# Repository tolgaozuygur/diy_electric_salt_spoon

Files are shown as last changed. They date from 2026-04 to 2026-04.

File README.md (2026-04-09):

# DIY Electric Salt Spoon
A DIY electro-gustation spoon that artificially increases the salty taste of foods using microscopic electric currents. Inspired by Kirin's Electric Salt Spoon and built as an open-source version to test the concept. Watch the <a href="https://www.youtube.com/watch?v=7jDd-lppwBE" target="_blank">build and testing video on YouTube</a> (EN subs available).

## Some components used not mentioned in the source files:
- 1mm 316L stainless steel wire in the spoon tip (to lower the risk of electrolysis and corrosion)
- 1mm copper plate as the hand electrode
- 12V 23A battery (small batteries commonly used in remotes)

## Scientific Background & Inspiration
The waveform blueprint and the core concept of this project are based on the electro-gustation research conducted by Miyashita Laboratory (Meiji University) and Kirin Holdings. 
You can read the original paper here:
- [Design of Electrical Stimulation Waveform for Enhancing Saltiness and Experiment on Low-Sodium Dieters](https://www.frontiersin.org/journals/virtual-reality/articles/10.3389/frvir.2022.879784/full) (Kaji, Sato, & Miyashita, 2022)

> ## ⚠️ SAFETY WARNING & DISCLAIMER
> **BUILD AND USE AT YOUR OWN RISK.**
> 
> This project involves passing an electrical current directly through the human body (specifically, from the hand to the tongue) to pull sodium ions towards your tongue for an increase in saltiness. While the circuit is designed with hardware current-limiting features to keep this current at microscopic, safe levels, human error in assembly can result in injury.
> 
> **CRITICAL POWER SUPPLY RULE:**
> When applying this device to a person, it must **ONLY** be powered by a small **12V 23A battery**. 
> * **NEVER** connect this device to a human while it is plugged into a USB port, a wall adapter, a bench power supply, or a high-current battery (like a standard 9V or LiPo). 
> * Doing so risks bypassing the safety limits, which can cause severe pain, chemical burns on the tongue, or serious electrical injury.
> 
> **Always test your fully assembled circuit with a multimeter** (you can place a 10kΩ resistor across the electrodes to simulate the hand-to-tongue resistance) to verify the output current is within the expected micro-amp range before ever letting it touch your skin or mouth.

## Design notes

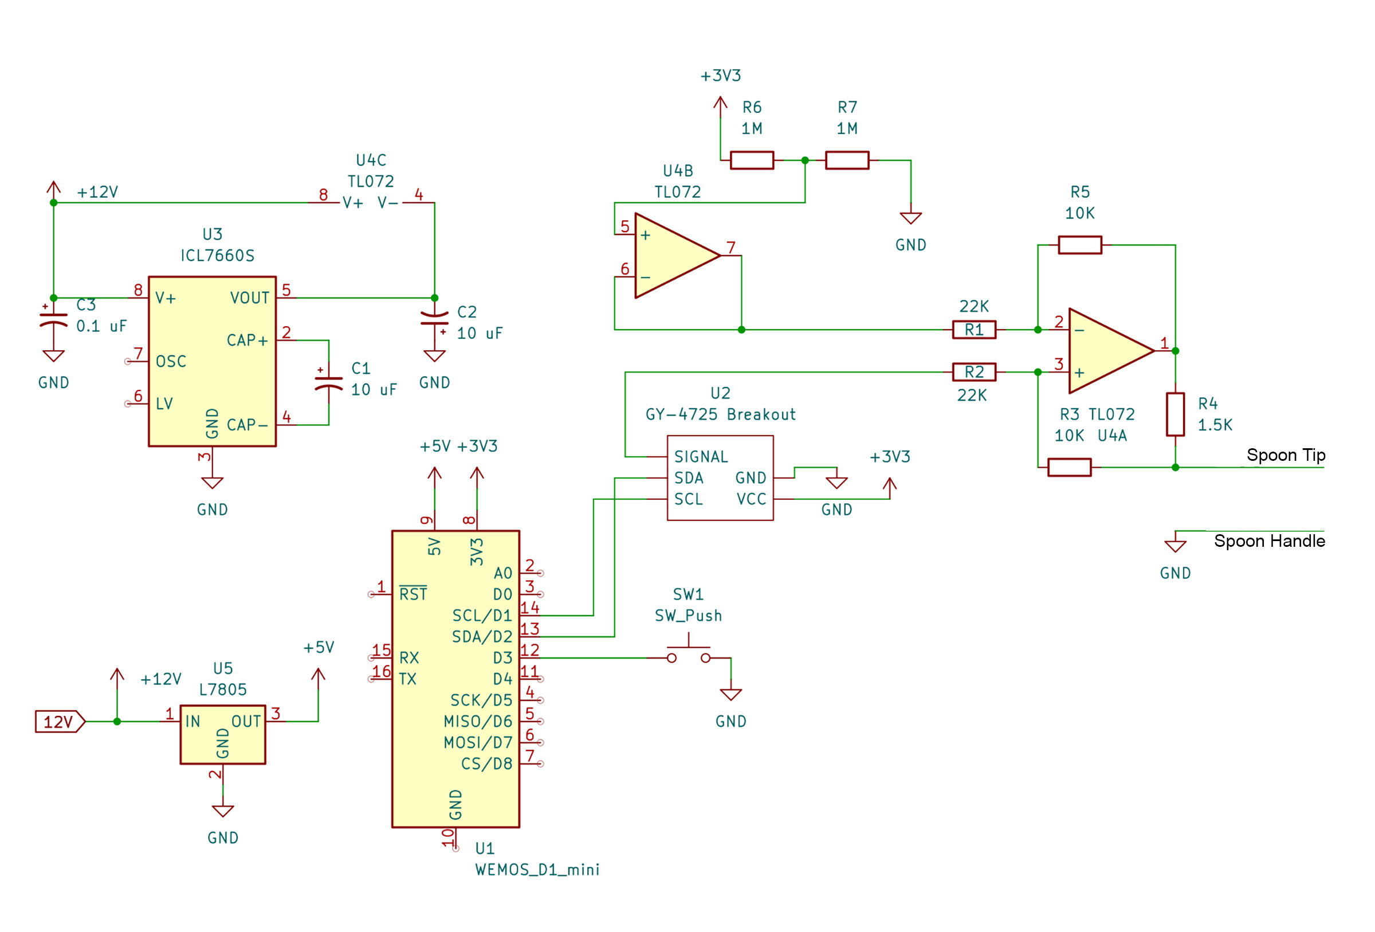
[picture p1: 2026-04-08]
electronics/schematics.jpg

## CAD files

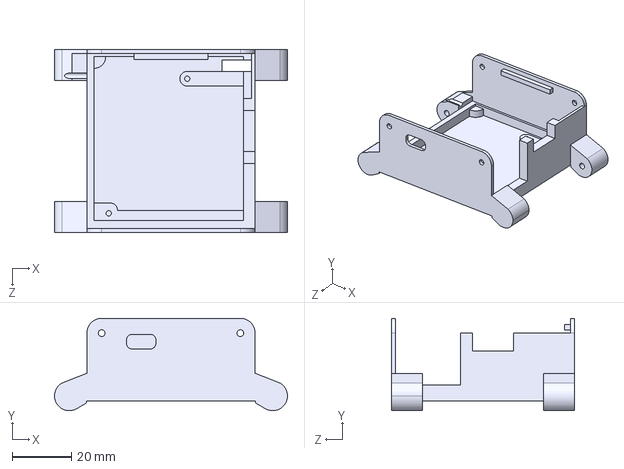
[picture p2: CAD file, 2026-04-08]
3d/case_base.STEP
78.9 x 31.3 x 62.0 mm

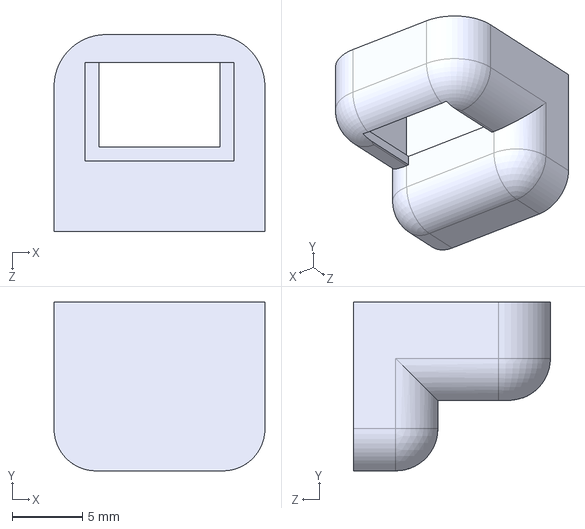
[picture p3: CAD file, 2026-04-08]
3d/spoon_socket_holder.STEP
15.0 x 12.0 x 14.0 mm

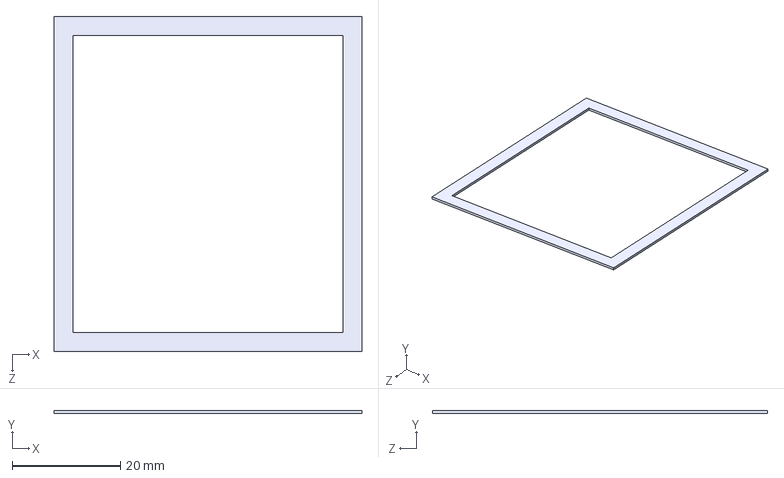
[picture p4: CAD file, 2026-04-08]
3d/case_electrode_mount.STEP
57.0 x 0.6 x 62.0 mm

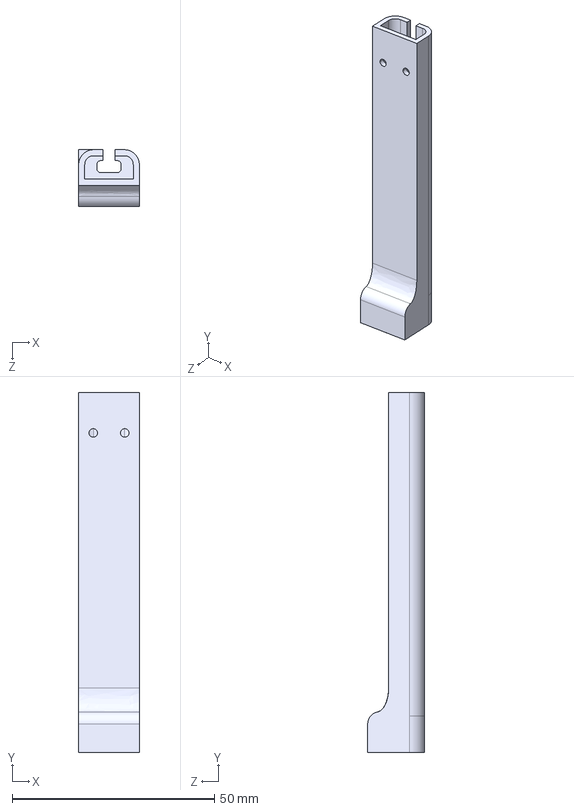
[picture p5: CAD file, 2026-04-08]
3d/spoon_middle.STEP
15.0 x 89.0 x 14.0 mm

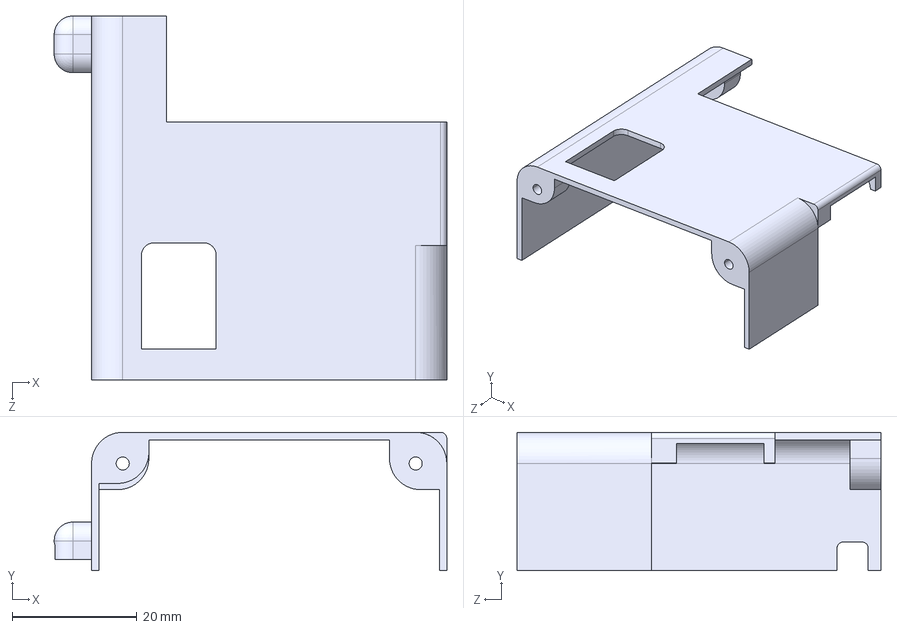
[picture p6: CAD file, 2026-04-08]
3d/case_cover.STEP
63.0 x 22.2 x 58.4 mm

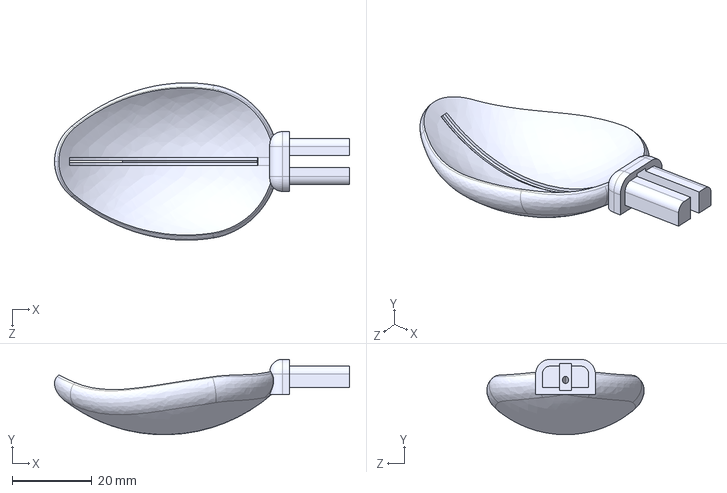
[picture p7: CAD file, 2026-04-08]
3d/spoon_tip.STEP
74.0 x 18.9 x 39.4 mm

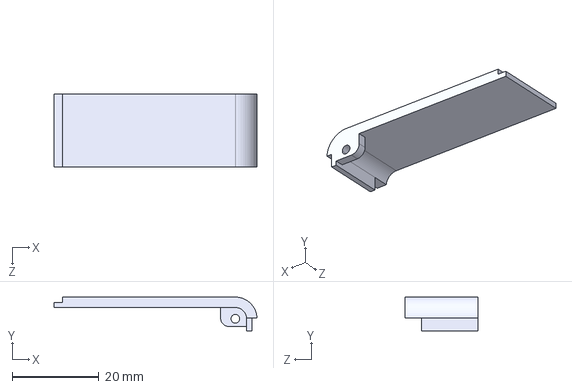
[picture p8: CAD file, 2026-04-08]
3d/battery_cap.STEP
46.8 x 7.80 x 16.8 mm

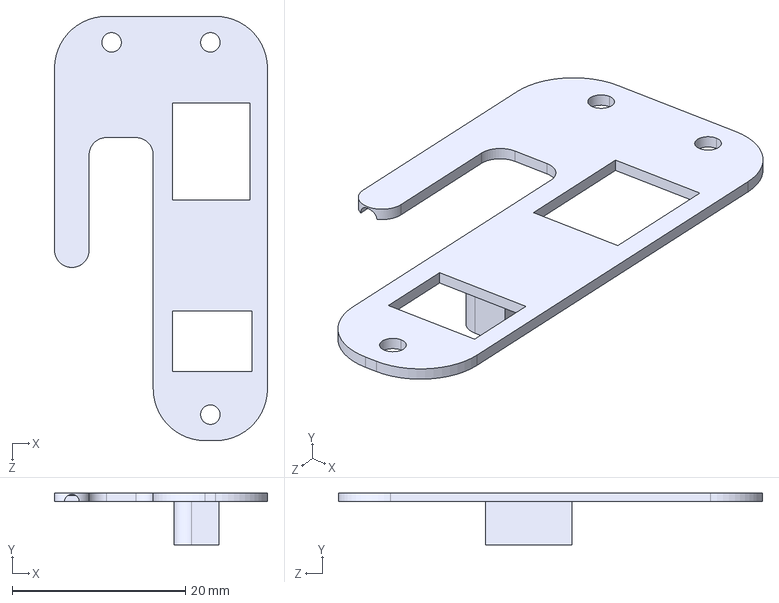
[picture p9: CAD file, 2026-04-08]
3d/cup_electrode_cover.STEP
24.6 x 6.00 x 49.0 mm

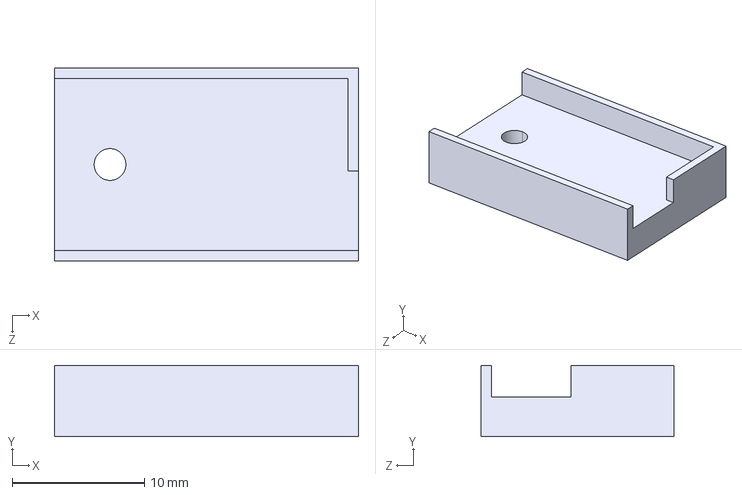
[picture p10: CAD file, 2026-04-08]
3d/battery_mount.STEP
23.0 x 5.40 x 14.6 mm

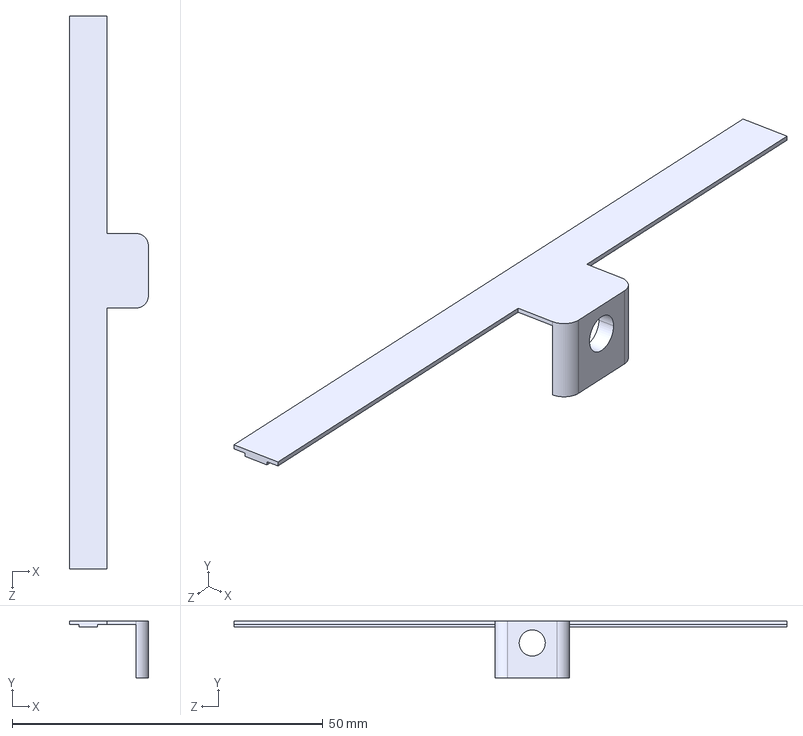
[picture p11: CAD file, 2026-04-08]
3d/spoon_stripe.STEP
12.7 x 9.10 x 89.0 mm

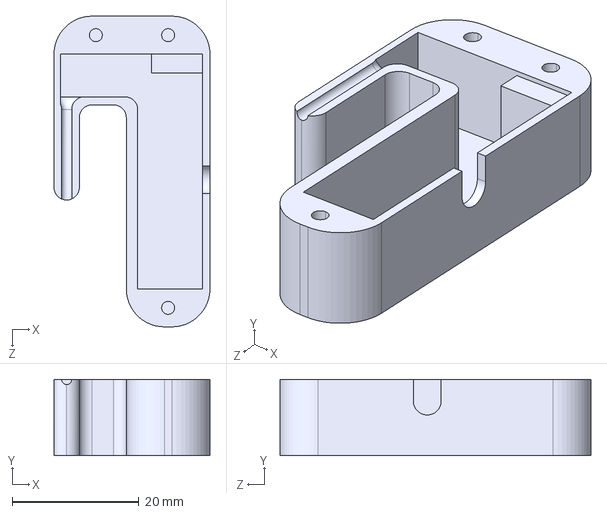
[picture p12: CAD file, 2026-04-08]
3d/cup_electrode.STEP
24.6 x 12.0 x 49.0 mm

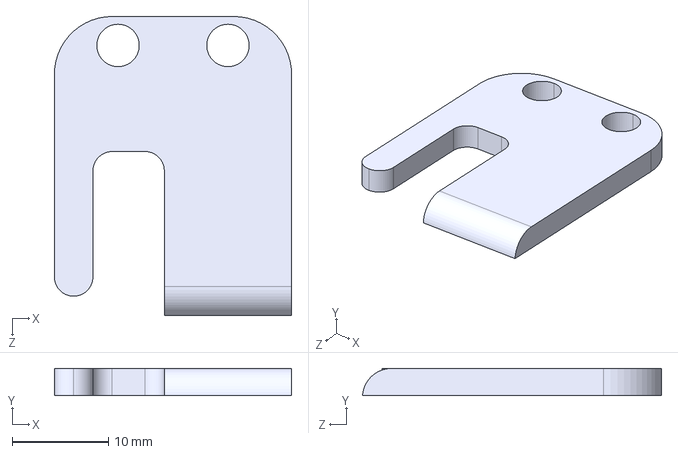
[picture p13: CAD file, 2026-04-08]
3d/cup_electrode_coverB.STEP
24.6 x 2.80 x 31.0 mm

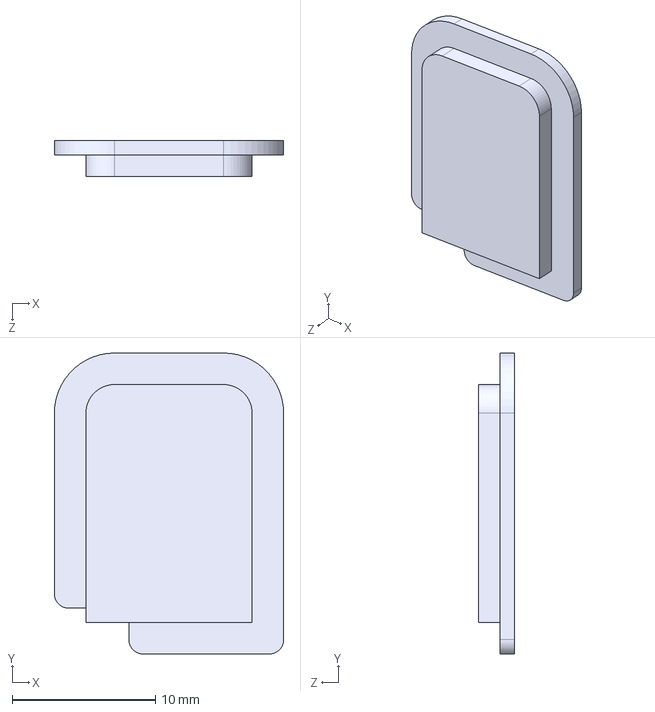
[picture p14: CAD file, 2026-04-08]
3d/case_window.STEP
16.0 x 21.0 x 2.50 mm

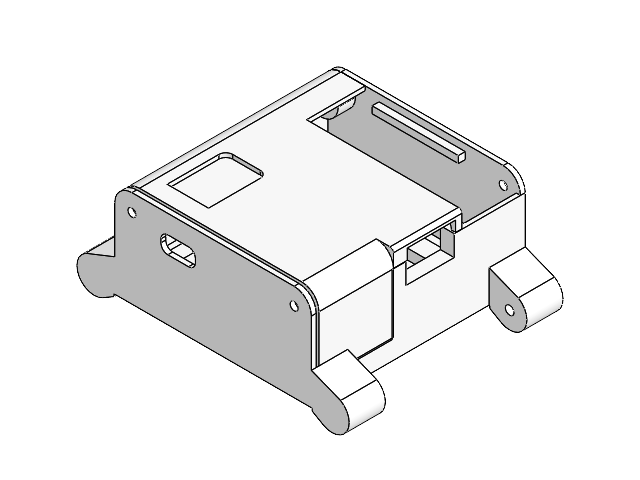
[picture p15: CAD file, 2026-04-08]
3d/spooncaseAssemb.SLDASM
case_base
case_cover

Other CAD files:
3d/spoonAssembly.SLDASM
3d/battery_cap.SLDPRT
3d/battery_mount.SLDPRT
3d/case_base.SLDPRT
3d/case_cover.SLDPRT
3d/case_electrode_mount.SLDPRT
3d/case_window.SLDPRT
3d/cup_electrode.SLDPRT
3d/cup_electrode_cover.SLDPRT
3d/cup_electrode_coverB.SLDPRT
3d/spoon_middle.SLDPRT
3d/spoon_socket_holder.SLDPRT
3d/spoon_stripe.SLDPRT
3d/spoon_tip.SLDPRT

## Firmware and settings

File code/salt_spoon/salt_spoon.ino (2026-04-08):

#include <Wire.h>
#include <Adafruit_MCP4725.h>
#include <ESP8266WiFi.h>
#include <ESP8266WebServer.h>
#include <EEPROM.h>
#include <math.h> 

extern "C" {
  #include "user_interface.h" 
}

#define DEBUG_MODE 0 

// --- ACCESS POINT CONFIGURATION ---
const char* ap_ssid = "SaltSpoon_Config";
const char* ap_password = "12345678";

// --- HARDWARE PINS ---
const int BUTTON_PIN = D3; 

Adafruit_MCP4725 dac;
static const uint8_t DAC_ADDR = 0x61; 
ESP8266WebServer server(80);

// --- HARDWARE CALIBRATION & EEPROM LIMITS ---
static const uint16_t DAC_MID = 1883;

// Master limits and defaults
static const float DEFAULT_CATHODAL_MA   = 0.50;
static const float MAX_CATHODAL_MA       = 0.57;

static const float DEFAULT_ANODAL_MA     = 0.67;
static const float MAX_ANODAL_MA         = 0.67;

static const uint16_t DEFAULT_REPEATS    = 1;
static const uint16_t MAX_REPEATS        = 20;

static const float DEFAULT_WAVE_SPEED    = 1.0;
static const float MIN_WAVE_SPEED        = 0.5;
static const float MAX_WAVE_SPEED        = 2.0;

static const uint16_t DEFAULT_ANODAL_MULT = 1;
static const uint16_t MIN_ANODAL_MULT     = 1;
static const uint16_t MAX_ANODAL_MULT     = 4;

// EEPROM Memory Addresses (Explicit byte mapping for safety)
const int addr_cathodal    = 0;   // float (4 bytes)
const int addr_anodal      = 4;   // float (4 bytes)
const int addr_repeats     = 8;   // uint16_t (2 bytes)
const int addr_speed       = 10;  // float (4 bytes)
const int addr_anodal_mult = 14;  // uint16_t (2 bytes)

// These will be loaded from EEPROM on boot
float target_cathodal_ma   = DEFAULT_CATHODAL_MA; 
float target_anodal_ma     = DEFAULT_ANODAL_MA;   
uint16_t target_repeats    = DEFAULT_REPEATS;
float wave_speed           = DEFAULT_WAVE_SPEED;
uint16_t anodal_multiplier = DEFAULT_ANODAL_MULT;

uint16_t intensity_cathodal = 0;
uint16_t intensity_anodal = 0;

// Update the step calculation whenever sliders change
void updateIntensities() {
  uint32_t c_steps = target_cathodal_ma * 3263.0;
  intensity_cathodal = constrain(c_steps, 0, 1859); 
  
  uint32_t a_steps = target_anodal_ma * 3263.0;
  intensity_anodal = constrain(a_steps, 0, 2187);   
}

// ── Base Waveform Timing (ms) ────────────────────────────────────────────────
static const uint32_t T_EASE_IN    = 300;  
static const uint32_t T_CATHODAL   = 500;  
static const uint32_t T_TRANSITION = 400;  
static const uint32_t T_ANODAL     = 500;  
static const uint32_t T_EASE_OUT   = 100;
static const uint32_t T_REST       = 100;

static const uint16_t EASE_STEPS   = 30;   
static const uint16_t RAMP_STEPS   = 40;   
// ─────────────────────────────────────────────────────────────────────────────

bool isConfigMode = false;

void setDAC(uint16_t value) {
  dac.setVoltage(constrain(value, 0, 4095), false);
}

// --- HTML WEB PAGE & SERVER LOGIC ---
void handleRoot() {
  String html = "<!DOCTYPE html><html><head><meta name='viewport' content='width=device-width, initial-scale=1.0'>";
  html += "<style>";
  html += "body { font-family: sans-serif; background-color: #f4f4f9; color: #333; padding: 20px; text-align: center; }";
  html += "h2 { color: #0056b3; }";
  html += ".card { background: white; padding: 20px; border-radius: 10px; box-shadow: 0 4px 8px rgba(0,0,0,0.1); margin-bottom: 20px; }";
  html += "input[type=range] { width: 100%; margin: 15px 0; }";
  html += "button { border: none; padding: 15px 20px; font-size: 16px; border-radius: 5px; cursor: pointer; width: 100%; font-weight: bold; margin-bottom: 10px; color: white;}";
  html += ".btn-save { background-color: #28a745; }";
  html += ".btn-save:active { background-color: #218838; }";
  html += ".btn-reset { background-color: #dc3545; }";
  html += ".btn-reset:active { background-color: #c82333; }";
  html += ".value-label { font-weight: bold; color: #d9534f; font-size: 1.2em; }";
  html += "</style></head><body>";
  
  html += "<h2>DIY Electric Salt Spoon</h2>";
  html += "<form action='/save' method='POST'>";
  
  // Cathodal Slider
  html += "<div class='card'>";
  html += "<label>Cathodal Phase (Negative Pull)</label><br>";
  html += "<span>Current: </span><span id='c_val' class='value-label'>" + String(target_cathodal_ma, 2) + "</span><span class='value-label'> mA</span>";
  html += "<input type='range' id='c_slider' name='cathodal' min='0.0' max='" + String(MAX_CATHODAL_MA, 2) + "' step='0.01' value='" + String(target_cathodal_ma, 2) + "' oninput=\"document.getElementById('c_val').innerText = this.value\">";
  html += "<small>Max limit: " + String(MAX_CATHODAL_MA, 2) + " mA</small>";
  html += "</div>";

  // Anodal Slider
  html += "<div class='card'>";
  html += "<label>Anodal Phase (Positive Push)</label><br>";
  html += "<span>Current: </span><span id='a_val' class='value-label'>" + String(target_anodal_ma, 2) + "</span><span class='value-label'> mA</span>";
  html += "<input type='range' id='a_slider' name='anodal' min='0.0' max='" + String(MAX_ANODAL_MA, 2) + "' step='0.01' value='" + String(target_anodal_ma, 2) + "' oninput=\"document.getElementById('a_val').innerText = this.value\">";
  html += "<small>Max limit: " + String(MAX_ANODAL_MA, 2) + " mA</small>";
  html += "</div>";

  // Repeats Slider
  html += "<div class='card'>";
  html += "<label>Waveform Repeats</label><br>";
  html += "<span>Cycles: </span><span id='r_val' class='value-label'>" + String(target_repeats) + "</span><span class='value-label'>x</span>";
  html += "<input type='range' id='r_slider' name='repeats' min='1' max='" + String(MAX_REPEATS) + "' step='1' value='" + String(target_repeats) + "' oninput=\"document.getElementById('r_val').innerText = this.value\">";
  html += "<small>Continuous loops</small>";
  html += "</div>";

  // Speed Slider
  html += "<div class='card'>";
  html += "<label>Global Wave Speed</label><br>";
  html += "<span>Speed: </span><span id='s_val' class='value-label'>" + String(wave_speed, 1) + "</span><span class='value-label'>x</span>";
  html += "<input type='range' id='s_slider' name='speed' min='" + String(MIN_WAVE_SPEED, 1) + "' max='" + String(MAX_WAVE_SPEED, 1) + "' step='0.1' value='" + String(wave_speed, 1) + "' oninput=\"document.getElementById('s_val').innerText = this.value\">";
  html += "<small>1.0x is normal, 2.0x is double speed</small>";
  html += "</div>";

  // Anodal Hold Multiplier Slider
  html += "<div class='card'>";
  html += "<label>Anodal Hold Duration</label><br>";
  html += "<span>Multiplier: </span><span id='am_val' class='value-label'>" + String(anodal_multiplier) + "</span><span class='value-label'>x</span>";
  html += "<input type='range' id='am_slider' name='anodal_mult' min='" + String(MIN_ANODAL_MULT) + "' max='" + String(MAX_ANODAL_MULT) + "' step='1' value='" + String(anodal_multiplier) + "' oninput=\"document.getElementById('am_val').innerText = this.value\">";
  html += "<small>Extends the positive push phase duration (1x to 4x)</small>";
  html += "</div>";

  // Action Buttons
  html += "<button type='submit' name='action' value='save' class='btn-save'>Save to Device Memory</button>";
  html += "<button type='submit' name='action' value='reset' class='btn-reset'>Reset to Defaults</button>";
  html += "</form>";
  html += "</body></html>";
  
  server.send(200, "text/html", html);
}

void handleSave() {
  if (server.hasArg("action")) {
    String action = server.arg("action");
    
    if (action == "reset") {
      // Apply Defaults
      target_cathodal_ma = DEFAULT_CATHODAL_MA;
      target_anodal_ma   = DEFAULT_ANODAL_MA;
      target_repeats     = DEFAULT_REPEATS;
      wave_speed         = DEFAULT_WAVE_SPEED;
      anodal_multiplier  = DEFAULT_ANODAL_MULT;
    } 
    else if (action == "save" && server.hasArg("cathodal") && server.hasArg("anodal") && server.hasArg("repeats") && server.hasArg("speed") && server.hasArg("anodal_mult")) {
      // Apply custom slider values with safety clamps
      target_cathodal_ma = constrain(server.arg("cathodal").toFloat(), 0.0, MAX_CATHODAL_MA);
      target_anodal_ma   = constrain(server.arg("anodal").toFloat(), 0.0, MAX_ANODAL_MA);
      target_repeats     = constrain(server.arg("repeats").toInt(), 1, MAX_REPEATS);
      wave_speed         = constrain(server.arg("speed").toFloat(), MIN_WAVE_SPEED, MAX_WAVE_SPEED);
      anodal_multiplier  = constrain(server.arg("anodal_mult").toInt(), MIN_ANODAL_MULT, MAX_ANODAL_MULT);
    }

    // Write everything to EEPROM
    EEPROM.put(addr_cathodal, target_cathodal_ma);
    EEPROM.put(addr_anodal, target_anodal_ma);
    EEPROM.put(addr_repeats, target_repeats); 
    EEPROM.put(addr_speed, wave_speed);
    EEPROM.put(addr_anodal_mult, anodal_multiplier);
    EEPROM.commit();
    
    // Recalculate DAC steps
    updateIntensities();
    
    // Success feedback
    String message = (action == "reset") ? "Factory Reset Complete!" : "Saved Successfully!";
    String html = "<html><head><meta name='viewport' content='width=device-width, initial-scale=1.0'><meta http-equiv='refresh' content='1;url=/'></head>";
    html += "<body style='font-family: sans-serif; text-align: center; padding: 50px;'>";
    html += "<h2 style='color: #28a745;'>" + message + "</h2><p>Returning to dashboard...</p></body></html>";
    server.send(200, "text/html", html);
  } else {
    server.send(400, "text/plain", "Bad Request");
  }
}

// --- WAVEFORM EXECUTION ---
void fireWaveform() {
  const uint16_t val_rest     = DAC_MID;
  const uint16_t val_cathodal = DAC_MID - intensity_cathodal;
  const uint16_t val_anodal   = DAC_MID + intensity_anodal;
  
  // Apply global wave_speed multiplier to step timings
  uint32_t ease_step_us  = ((T_EASE_IN * 1000) / EASE_STEPS) / wave_speed;
  uint32_t trans_step_us = ((T_TRANSITION * 1000) / RAMP_STEPS) / wave_speed;

  for (uint16_t i = 0; i <= EASE_STEPS; i++) {
    float t = (float)i / EASE_STEPS; 
    float curve = 1.0 - cos(t * PI / 2.0); 
    uint16_t val = val_rest - (intensity_cathodal * curve);
    setDAC(val);
    delayMicroseconds(ease_step_us);
  }

  setDAC(val_cathodal);
  delay(T_CATHODAL / wave_speed);

  uint16_t total_swing = intensity_cathodal + intensity_anodal;
  for (uint16_t i = 0; i <= RAMP_STEPS; i++) {
    float t = (float)i / RAMP_STEPS;
    uint16_t val = val_cathodal + (total_swing * t); 
    setDAC(val);
    delayMicroseconds(trans_step_us);
  }

  setDAC(val_anodal);
  
  // Apply BOTH the global wave speed and the isolated Anodal Multiplier
  delay((T_ANODAL * anodal_multiplier) / wave_speed);

  for (uint16_t i = 0; i <= EASE_STEPS; i++) {
    float t = (float)i / EASE_STEPS; 
    float curve = cos(t * PI / 2.0); 
    uint16_t val = val_rest + (intensity_anodal * curve);
    setDAC(val);
    delayMicroseconds(ease_step_us); 
  }

  setDAC(val_rest);
  delay(T_REST / wave_speed);
}

void setup() {
  Serial.begin(115200);
  pinMode(LED_BUILTIN, OUTPUT);
  pinMode(BUTTON_PIN, INPUT_PULLUP);
  
  digitalWrite(LED_BUILTIN, LOW); 

  // --- INITIALIZE EEPROM ---
  EEPROM.begin(512); 
  EEPROM.get(addr_cathodal, target_cathodal_ma);
  EEPROM.get(addr_anodal, target_anodal_ma);
  EEPROM.get(addr_repeats, target_repeats);
  EEPROM.get(addr_speed, wave_speed);
  EEPROM.get(addr_anodal_mult, anodal_multiplier);
  
  // Clean sanity check
  if (isnan(target_cathodal_ma) || target_cathodal_ma < 0.0 || target_cathodal_ma > MAX_CATHODAL_MA) {
    target_cathodal_ma = DEFAULT_CATHODAL_MA; 
  }
  if (isnan(target_anodal_ma) || target_anodal_ma < 0.0 || target_anodal_ma > MAX_ANODAL_MA) {
    target_anodal_ma = DEFAULT_ANODAL_MA;
  }
  if (target_repeats < 1 || target_repeats > MAX_REPEATS) {
    target_repeats = DEFAULT_REPEATS;
  }
  if (isnan(wave_speed) || wave_speed < MIN_WAVE_SPEED || wave_speed > MAX_WAVE_SPEED) {
    wave_speed = DEFAULT_WAVE_SPEED;
  }
  if (anodal_multiplier < MIN_ANODAL_MULT || anodal_multiplier > MAX_ANODAL_MULT) {
    anodal_multiplier = DEFAULT_ANODAL_MULT;
  }
  
  updateIntensities();
  
  Serial.println("\n--- BOOTING ---");
  Serial.println("Press button now for Config Mode...");

  // Delayed Boot Timer
  uint32_t bootTimer = millis();
  while (millis() - bootTimer < 3000) {
    if (digitalRead(BUTTON_PIN) == LOW) {
      isConfigMode = true;
      break; 
    }
    delay(10);
  }

  if (isConfigMode) {
    Serial.println("\nConfig Mode Activated.");
    
    WiFi.mode(WIFI_AP);
    WiFi.softAP(ap_ssid, ap_password); 
    
    Serial.print("Access Point Started: ");
    Serial.println(ap_ssid);
    Serial.print("Permanent IP Address: ");
    Serial.println(WiFi.softAPIP()); 

    // Route web traffic
    server.on("/", HTTP_GET, handleRoot);
    server.on("/save", HTTP_POST, handleSave);
    server.begin();
    
  } else {
    Serial.println("\nTaste Mode Activated. Entering Light Sleep.");
    digitalWrite(LED_BUILTIN, HIGH); 

    Wire.begin();  
    Wire.setClock(400000); 
    if (!dac.begin(DAC_ADDR)) {
      while (true) { 
        digitalWrite(LED_BUILTIN, LOW); delay(100);
        digitalWrite(LED_BUILTIN, HIGH); delay(100);
      } 
    }
    setDAC(DAC_MID); 

    WiFi.disconnect(true);
    WiFi.mode(WIFI_OFF);
    WiFi.forceSleepBegin();
    delay(1); 

    wifi_set_opmode(NULL_MODE);
    wifi_fpm_set_sleep_type(LIGHT_SLEEP_T);
    wifi_fpm_open();
  }
}

void loop() {
  if (isConfigMode) {
    server.handleClient();

    static uint32_t lastBlink = 0;
    static bool ledState = false;
    if (millis() - lastBlink >= 1000) {
      lastBlink = millis();
      ledState = !ledState;
      digitalWrite(LED_BUILTIN, ledState ? LOW : HIGH);
    }

  } else {
    gpio_pin_wakeup_enable(GPIO_ID_PIN(0), GPIO_PIN_INTR_LOLEVEL);
    
    wifi_fpm_do_sleep(0xFFFFFFF); 
    delay(10); 
    
    Serial.print("Button Pressed! Firing Waveform ");
    Serial.print(target_repeats);
    Serial.println(" times...");
    
    digitalWrite(LED_BUILTIN, LOW); 

    for (uint16_t r = 0; r < target_repeats; r++) {
      fireWaveform();
      
      if (r < target_repeats - 1) {
        digitalWrite(LED_BUILTIN, HIGH); 
        delay(100);                      
        digitalWrite(LED_BUILTIN, LOW);  
      }
    }

    digitalWrite(LED_BUILTIN, HIGH); 
    Serial.println("Sequence Complete. Going back to sleep...");
    
    while (digitalRead(BUTTON_PIN) == LOW) {
      delay(10); 
    }
    delay(250); 
  }
}

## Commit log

2026-04-08 Added all source files
    [battery_cap.SLDPRT, battery_cap.STEP, battery_mount.SLDPRT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]
2026-04-08 Fixed an error in the schematics
    The voltage converter was shown as ICL7660, it should be ICL7660S or it will generate a magic smoke instead of -12V
2026-04-08 Delete electronics/salt_spoon directory
    These kicad files have a critically mislabeled component. Will update
    [salt_spoon.kicad_pcb, salt_spoon.kicad_sch]
2026-04-08 Added fixed kicad files
    Fixed the mislabeled ICL7660S
    [salt_spoon.kicad_pcb, salt_spoon.kicad_sch]
